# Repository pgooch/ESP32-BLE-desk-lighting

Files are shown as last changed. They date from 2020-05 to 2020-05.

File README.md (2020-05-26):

# ESP32-BLE-desk-lighting
This repository contains the Arduino IDE project, the electron/HTML controller, and the printable half case STL file for my ESP32 based bluetooth controlled desk lighting. 

## Why?
The previous owner of my house decided to install halogen based lighting in the bedroom that became my office. This is nice when you drop something and want to light the entire room up, but normally it's to much light and more importantly durning the summer too much heat. 

In additional to that when I build my new keyboard I decided to forego the backlight mostly because I didn't like the way it looked on the keycaps I'm using, general laziness is also a factor, I've taken apart and built the same keyboard a few times at this point and I wasn't excited about the prospect over another 280 solder joints.

## Materials
I used the following items for this setup.
* Approximately 1 meter of WS2812 compatible LEDs for the back of monitor lighting.
    * I suggest side shooting LEDs, I used these: https://www.aliexpress.com/item/32922687661.html
* About another meter of generic WS2812 strip for the under desk
    * I had some kicking around, inevitably also from AliExpress
* A few 470ohm resistors installed on the data line per the Adafruit NeoPixels Uberguide.
* A power supply capable of power the LEDs your using and a way to get that power to the board, I used a 5v 15amp one that came with a female barrel jack.
* An ESP32 based development board with USB serial driver (or a way to program a bare one).
* Some 3 core wire, as well as various other bits of wire for power.
* A solderable double 1/2 breadboard, I used one from ElectroCookie via Amazon
* Wire and connectors as needed, I used JSX connectors but you could solder it all together directly.
* A 3d printer to print a little case, totally optional but it makes mounting it easier.

## Wiring
Wiring is simple. I took a Female Barrel plus and connected it to the +/- rails, then I connected my LED strips to pins 12, 13, and 25 for the left monitor, right monitor and under desk lights respectively.

You'll also need to make some wires to run between the strips and the control unit, I used 3 core wire for MaxBrite and make adapters from the PCB plus to the LED strip plugs.

## The case
The case was made in fusion360 and can be printed in any material, I used a nifty teal PLA. It's a pretty basic print and setting can be more or less whatever prints best for you. There are screw holes in it, however you can fill them with glue and screw into that if they don't work after printing (their tiny 2mm screws so it's hard to get them to print threads cleanly).

## Building the control app
After running `npm install` you should be able to build the app for your current platform by navigating to the app directory and running `electron-packager .`. This is the primary way I use the app, to occasionally change color or brightness. You can also point a vhost to the src directory and it should work as a hosted webpage, however the page must be hosted, not at `file://` and it will need to be a secure domain or the browser will need to be told to ignore that. Overall it was kinda a fiddly process so I just use the app (because macOS update reset vhosts every update now).

## ToDo
* The color picker seems to not update the other points when you set the value via JS, thats probably more picker than implementation from what I've read but I didn't get to deep into it.
* I'm not entirely sure how it handles various power cycling possibilities, however it seems to be able to recover well enough for my use case.
* The electron app does not build with an icon, I'm not sure why it all appears to be properly configured, from reading it seems to be a not to uncommon problem.
* A better readme and some pictures might be nice, but as I'm writing this I'm still waiting on components for final assembly. Also a video of the build process, but that feels more like a V2 thing.

## Future features
* I'm been thinking of getting a motorized sit/stand desk conversion, controlling height with this system would be pretty cool and should be doable from what I've read on the subject.
* A passive IR sensor could potentially turn the LEDs on/off when you sit down or leave from your desk. I don't currently have a suitable one but an order has been placed.
* Space was left on the PCB for a third monitor, however I can't run 3 4k60 displays on my machine without an external GPU and I don't really feel like taking on that cost for another screen I don't really need.

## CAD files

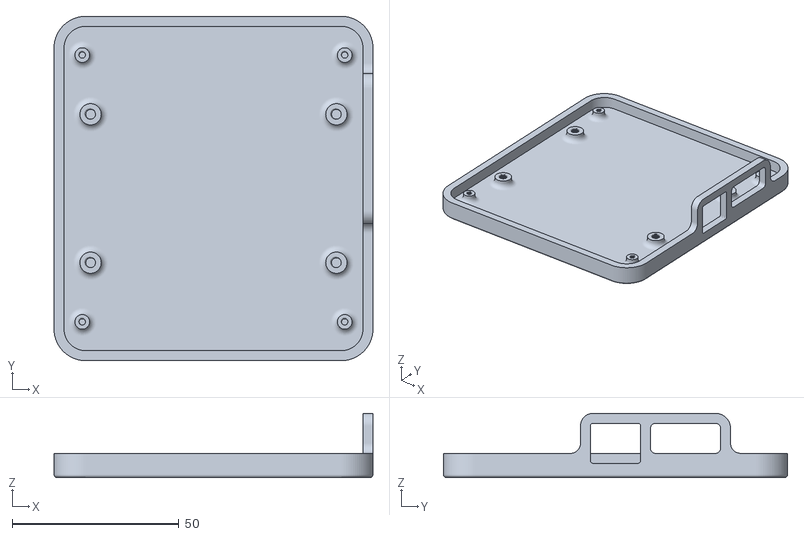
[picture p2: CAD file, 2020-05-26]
Double Half Breadboard Half Case.stl
95.7 x 103.2 x 19.3

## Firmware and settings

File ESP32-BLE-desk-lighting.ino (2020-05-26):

// Import all the things
#include <BLEDevice.h>
#include <BLEUtils.h>
#include <BLEServer.h>
#include <NeoPixelBus.h>

/*
 * UUID managment. 
 * This could probably be a library but since I am not generating the UUIDs the proper way I'll just leave the hack as is.
 */
#define UUID_BASE "4fafc201-1fb5-459e-8fcc-000000000000" // The base shouls end with 12 0's but be different for every device
int UUID_COUNT = 0;
// This function generates a UUID
char* getUUID(int service = 0, int characteristic = 0xfffffff){
  // Copy over the base UUID
  char* FinalUUID = new char[37];
  memmove(FinalUUID,UUID_BASE,37);

  // Add the incrementing bit
  char hex[12]; 
  itoa(UUID_COUNT,hex,16);
  int hexLength = strlen(hex);
  memmove(FinalUUID+36-hexLength,hex,hexLength);

  // Outout a little debug info
//  Serial.print("UUID generated for service ");
//  Serial.print(serviceHex);
//  Serial.print(" characteristic ");
//  Serial.print(characteristicHex);
//  Serial.print(" as ");
//  Serial.println(FinalUUID);

  // Tick the number up and return
  UUID_COUNT++;
  return FinalUUID;
}

// Structures for some additional data I'm going to need to use.
typedef struct {
  char* name;
  int characteristics[2];
} BT_Service;
typedef struct {
  char* name;
  std::string value;
} BT_Characteristics;
typedef struct {
  int service;
  int characteristic;
  std::string value;
} BT_Values;

// Prepare for the BT connection and sever
#define DEVICE_NAME "ESP32 BT Desk Lighting"
BT_Service Features[] = {
  // Name, Characteristics, LED Strip
  {"System",              {3}   },
  {"Left Monitor Light",  {2,1} },
  {"Right Monitor Light", {2,1} },
  {"Under Desk Light",    {2,1} },
};
BT_Characteristics Options[] = {
  // Name, Default
  {"NULL",        "NULL"}, // This intentially not used so empty array spaces will auto filter out
  {"Color",       "#FFBB55"},
  {"Brightness",  "512"}, // No longer used, must switch back to NeoPixelBrightnessBus to use again.
  {"Power",       "On"},
};
// Here are some magic numbers, since it needs to know values at runtime and won't run any code to calculate them.
const int FeatureCount = 4; //Count be sizeof(Features)/sizeof(Features[0]);, it's the number of services
const int OptionCount = 7; // This is the sum of all non zero options acrosss all features

// Prepare some of the BLE arrays and a bool
BLEService *ServiceArray[FeatureCount];
BLECharacteristic *CharacteristicArray[OptionCount];
BT_Values CharacteristicValues[OptionCount];

// Create the LED strip, because we gotta use the RMT so we can have more than enough strips, they gotta be out in the open
NeoPixelBus<NeoGrbFeature, NeoEsp32Rmt0800KbpsMethod> s0strip(72, 12);
NeoPixelBus<NeoGrbFeature, NeoEsp32Rmt1800KbpsMethod> s1strip(72, 13);
NeoPixelBus<NeoGrbFeature, NeoEsp32Rmt2800KbpsMethod> s2strip(58, 25);
#define MIN_BRIGHTNESS 10
#define MAX_BRIGHTNESS 255

// Connection State managment, will restart advertising once a client has disconnected.
bool BLEDeviceConnected = false;
class ServerCallbacks: public BLEServerCallbacks {
    void onConnect(BLEServer* Server) {
      BLEDeviceConnected = true;
      BLEDevice::startAdvertising();
    };
    void onDisconnect(BLEServer* pServer) {
      BLEDeviceConnected = false;
    }
};




void setup(){
  Serial.begin(115200);
  Serial.println("\n");
  Serial.print("Setting up the ");
  Serial.println(DEVICE_NAME);

  // Init BLE
  BLEDevice::init(DEVICE_NAME);
  BLEServer *Server = BLEDevice::createServer();
  Server->setCallbacks(new ServerCallbacks());
  BLEAdvertising *Advertising = BLEDevice::getAdvertising();

  // loop the services, adding them as we go
  Serial.println("The following JSON can be used for the web interface:");
  Serial.println("{");
  Serial.print("\t\"_name\": \"");
  Serial.print(DEVICE_NAME);
  Serial.println("\",");
  int characteristicPointer = 0; // Needed for adding characteristincs, needs to keep counting between all services
  for(int s=0; s<FeatureCount; s++){
    char* serviceID = getUUID(s);
    ServiceArray[s] = Server->createService(serviceID);
    Advertising->addServiceUUID(serviceID);
    
    Serial.print("\t\"");
    Serial.print(Features[s].name);
    Serial.print("\": {\n");
    Serial.print("\t\t\"UUID\": \"");
    Serial.print(serviceID);
    Serial.print("\",\n");
    Serial.print("\t\t\"characteristics\": [\n");

    // Add the services characteristics
    int characteristicsInService = sizeof(Features[s].characteristics)/sizeof(Features[s].characteristics[0]);
    for(int c=0; c<characteristicsInService; c++){
      if(Features[s].characteristics[c]==0){
        // Were not gonna deal with zeros
        
      }else{
        char* charUUID = getUUID(s,c);

        // Add the comma and line break on every after the first
        if(c>0){
          Serial.print(",");
          Serial.print("\n");
        }
        Serial.print("\t\t\t");

        Serial.print("{\"");
        Serial.print(Options[Features[s].characteristics[c]].name);
        Serial.print("\": \"");
        Serial.print(charUUID);
        Serial.print("\"}");
  
        CharacteristicArray[characteristicPointer] = ServiceArray[s]->createCharacteristic(charUUID,BLECharacteristic::PROPERTY_READ | BLECharacteristic::PROPERTY_WRITE);
        CharacteristicArray[characteristicPointer]->setValue(Options[Features[s].characteristics[c]].value);
        CharacteristicValues[characteristicPointer] = {s,Features[s].characteristics[c],""};
        characteristicPointer++;
      }
    }
    
    Serial.print("\n");
    Serial.print("\t\t]\n");
    Serial.print("\t}");
    if(s<FeatureCount-1){
      Serial.print(",");
    }
    Serial.print("\n");

    // Now that everything is prepped we can start the ble service and clean up that JSON
    ServiceArray[s]->start();
  }
  Serial.println("}");

  // Advertise we got that bluetooth going on
  Advertising->setScanResponse(true);
  Advertising->setMinPreferred(0x06);
  BLEDevice::startAdvertising();
  Serial.println("Setup Complete, starting initial update.");

  // Prep the LEDs
  for(int f=0; f<FeatureCount; f++){
    switch(f){
      case 0:
        s0strip.Begin();
      break;
      case 1:
        s1strip.Begin();
      break;
      case 2:
        s2strip.Begin();
      break;
      default:
      break;
    }
  }
};


// Loop through all the characteristcs, if one has changed figure out the details
bool lightsOn = true;
void loop(){
  for(int c=0; c<OptionCount; c++){
    if(CharacteristicValues[c].value != CharacteristicArray[c]->getValue()){

      // Update the previous with the new previious
      CharacteristicValues[c].value = CharacteristicArray[c]->getValue();

      // First and foremost, if it's off set the strip to black (not really off but I'm not worried about sleeping it at this time
      if(Options[CharacteristicValues[c].characteristic].name=="Power"){
        const char* state = CharacteristicArray[c]->getValue().c_str();
        // If on then change slightsOn and clear the stored values so the below will reprocess.
        if(!lightsOn && strcmp(state,"On")==0){
          // Serial.println("Lights turned on");
          lightsOn = true;
          for(int c=0; c<OptionCount; c++){
            CharacteristicValues[c].value = "";
          }

        // zif your turning it off then clear the LED strips back to solid black.
        }else if(lightsOn && strcmp(state,"Off")==0){
          // Serial.println("Lights turned off");
          lightsOn = false;
          RgbColor color(0,0,0);
          s0strip.ClearTo(color);
          s0strip.Show();
          s1strip.ClearTo(color);
          s1strip.Show();
          s2strip.ClearTo(color);
          s2strip.Show();
        }

      // Update things as needed, starting with color
      }else if(Options[CharacteristicValues[c].characteristic].name=="Color"){
        // Parse the HTML color (the built in thing is not working)
        const char* string = CharacteristicArray[c]->getValue().c_str();
        // lifted from https://stackoverflow.com/questions/28104559/arduino-strange-behavior-converting-hex-to-rgb cause bit shifting is scary
        long number = (long) strtol( &string[1], NULL, 16);
        int r = number >> 16;
        int g = number >> 8 & 0xFF;
        int b = number & 0xFF;
        RgbColor color(r,g,b);
        
        // Set strip color and update
        // Serial.print("Updating color for ");
        // Serial.print(Features[CharacteristicValues[c].service].name);
        // Serial.print(" to ");
        // Serial.print(r);
        // Serial.print(",");
        // Serial.print(g);
        // Serial.print(",");
        // Serial.print(b);
        if(Features[CharacteristicValues[c].service].name == "Left Monitor Light"){
            s0strip.ClearTo(color);
            s0strip.Show();
            // Serial.println(" done.");
        }else if(Features[CharacteristicValues[c].service].name == "Right Monitor Light"){
            s1strip.ClearTo(color);
            s1strip.Show();
            // Serial.println(" done.");
        }else if(Features[CharacteristicValues[c].service].name == "Under Desk Light"){
            s2strip.ClearTo(color);
            s2strip.Show();
            // Serial.println(" done.");
        }else{
          Serial.println(" ERROR; no addressable LED strip for service.");
        }


 
      // the brighness is much simpler, and disabled since I'm no longer using the brightness bus due to how it morphs colors
      }else if(Options[CharacteristicValues[c].characteristic].name=="Brightness"){
      /*
        int b = atoi(CharacteristicArray[c]->getValue().c_str());
        b = map(b,0,1023,MIN_BRIGHTNESS,MAX_BRIGHTNESS);

        Serial.print("Updating brightness for ");
        Serial.print(Features[CharacteristicValues[c].service].name);
        Serial.print(" to ");
        Serial.print(b);
       if(Features[CharacteristicValues[c].service].name == "Left Monitor Light"){
            s0strip.SetBrightness(b);
            s0strip.ClearTo(b);
            s0strip.Show();
            Serial.println(" done.");
        }else if(Features[CharacteristicValues[c].service].name == "Right Monitor Light"){
            s1strip.SetBrightness(b);
            s1strip.Show();
            Serial.println(" done.");
        }else if(Features[CharacteristicValues[c].service].name == "Under Desk Light"){
            s2strip.SetBrightness(b);
            s2strip.Show();
            Serial.println(" done.");
        }else{
          Serial.println(" ERROR; no addressable LED strip for service.");
        }
      */

      // Ya done goofed (or the update is passive)
      }else{
        Serial.print("Unable to update the \"");
        Serial.print(Features[CharacteristicValues[c].service].name);
        Serial.print("\" features \"");
        Serial.print(Options[CharacteristicValues[c].characteristic].name);
        Serial.print("\" option to \"");
        Serial.print(CharacteristicValues[c].characteristic);
        Serial.println("\", no appropriate update logic found.");
      }
    }
  }
  delay(1);
};

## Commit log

2020-05-12 Initial Commit
    This is actually a kinda elaborate way to do this with loops and references and all that. Seems great, however I have come up with a far more straight foward method. I just didn't want to lose this code.
    [ESP32-BLE-desk-lighting.ino]
2020-05-26 All working except for the testing.
    I don't have all my strips wired up for an all in place test but the individual parts all work independently so I think it'll be fine.
2020-05-26 Menubar App to Normal App
    Ad additional refinements to how it's all sorted out.
    [Double Half Breadboard Half Case.stl]
